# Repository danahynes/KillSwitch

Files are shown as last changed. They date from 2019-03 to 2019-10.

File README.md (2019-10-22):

# KillSwitch

Source code and binaries for the KillSwitch project
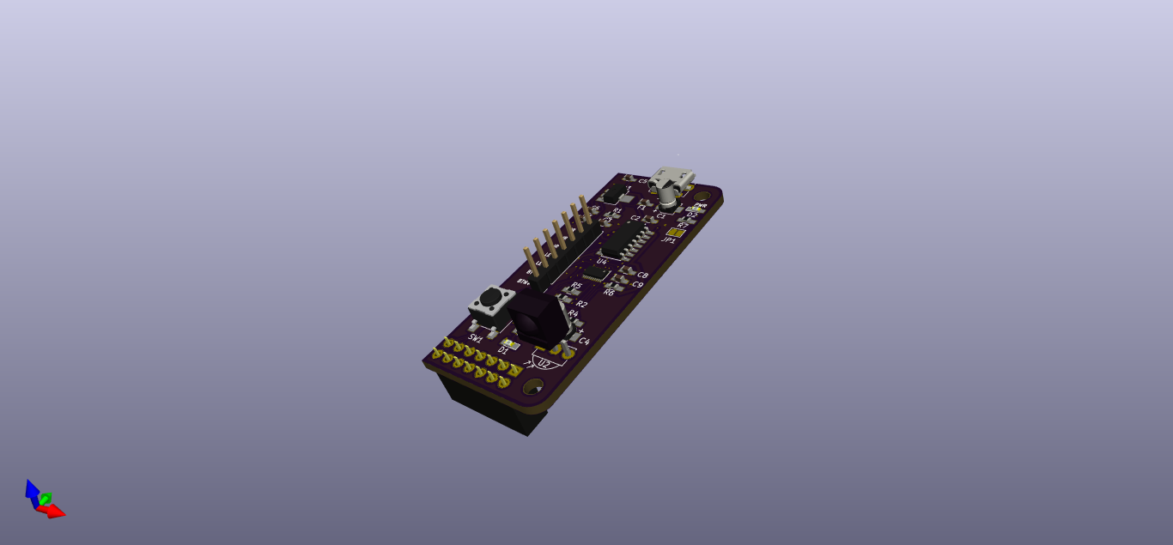
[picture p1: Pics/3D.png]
3D Image


## About
KillSwitch is a small PCB that attaches to your Raspberry Pi 2/3/4/0 (40 pin GPIO) and allows you to turn the Pi on or off using a push button or an IR remote. It is compatible with almost any infrared remote control, or IR blaster devices like the [Harmony Hub](https://www.logitech.com/en-us/product/harmony-hub) or
[SparkFun WiFi IR Blaster](https://www.sparkfun.com/products/15031). It has been tested with Raspbian and RetroPie. There are three parts to KillSwitch:

1. The hardware (the actual PCB)
2. The software (code that runs on the Raspberry Pi)
3. The firmware (code that runs on the PCB)

## Hardware
The first thing you need is the actual circuit board. The KillSwitch hardware files are included in the download, including a schematic and a PCB layout in KiCad 5 for both the Raspberry Pi 2/3/4 and the Zero. You can get the PCB made by the vendor of your choice (I used OSH Park, hence the purple PCB in the picture above) or breadboard it using the schematic.

## Software installation
To download and install the KillSwitch software on your Pi, first go to the [latest release](https://github.com/danahynes/KillSwitch/releases/latest). Click the link for the "Source code (zip)" or "Source code (tar.gz)" file. Download and extract the file. Then open a terminal, ```cd``` to the KillSwitch-N.N.N/Software/Bash folder, and type:
~~~~
sudo ./killswitch-install.sh
~~~~

Here is a one-line command that will do everything for you:
~~~~
cd && curl -O https://raw.githubusercontent.com/danahynes/KillSwitch/master/killswitch-install-latest.sh && bash killswitch-install-latest.sh
~~~~
You can safely delete the "killswitch-install-latest.sh" file in your home folder after rebooting.

You can also clone the latest "bleeding edge" code by running this command:
~~~~
git clone https://github.com/danahynes/KillSwitch
~~~~
then ```cd``` into the KillSwitch/Software/Bash folder and type:
~~~~
sudo ./killswitch-install.sh
~~~~

The software requires an OS of Raspbian Jessie or newer, or any other OS that
uses "systemd". If you're not sure, Google is your friend -)

## A note on the Pi serial ports
The Raspberry Pi has two UARTs, one based on hardware, and one based on software.

The hardware UART is faster and more reliable, since the silicon is specifically designed to do one thing, and one thing only, and do it well. On the Raspberry Pi 3 (and newer), this port is, by default, used for Bluetooth for obvious reasons.

The software UART on the Pi is normally used for serial login (the ability to log into, and control, the Pi over a wired RS-232 serial connection). This port is reconfigured by KillSwitch to allow communication between the device and the Pi.

That means that installing the software will turn off your ability to log in to the Pi using a serial console (getty/putty), as the software serial port (physical pins 8 and 10, labeled BCM 14 & BCM 15, and in Linux is known as /dev/ttyS0) is used to communicate to the device when using the settings script. If you don't know what this means, don't worry. You'll probably never use this feature. This does not affect the ability to use SSH or VNC to connect to the Pi, only to log in using getty or putty over a physical serial connection.

## Firmware installation
XXXXXXXXXXXXXXXXXXXXXXXXXXXXXXXXXXXX\
THIS DOES NOT WORK - NEED TO PROGRAM ATTINY BEFORE FIRST USE\
XXXXXXXXXXXXXXXXXXXXXXXXXXXXXXXXXXXX\
To install the firmware for the first time, you do not need a programmer, you can use the settings menu on the Pi. Make sure that the software is correctly installed on the Pi, then attach the KillSwitch device to your Pi. **Make sure to plug the power cord into the Pi, not the KillSwitch.** Open a terminal and type "killswitch-settings.sh". Then select the "Update" menu item. This will install/update the firmware on your device and the software on your Pi, if necessary.

## First use
To set up your KillSwitch for the first time, follow these steps:
1. After following the above steps to install the software and firmware, attach the KillSwitch to your Pi and plug the power source in to the KillSwitch. The KillSwitch device uses the same USB Micro B power supply that the Pi uses, so you just have to move the plug from the Pi to the KillSwitch.
2. Press and hold the push button on the device until the LED flashes rapidly (The default is 5 seconds, but this can be changed using the Settings program, see below). Release the button.
3. Point the remote at the device's IR receiver and press the button on the remote that you want to use as the "On" button (note that you have 15 seconds before the device exits the programming mode). The status LED will flash once slowly, then flash rapidly again.
4. Press the button on the remote that you want to use as the "Off" button (again, you have 15 seconds before the device exits programming mode). It can be the same as the "On" button if you wish, creating a "toggle" button. The status LED will flash twice slowly, then turn off.

During programming, the button works in the following ways:
* If the button is held for Long Press Time, exit Programming mode, leaving any unrecorded codes unchanged.
* If the button is pressed quickly, and you are currently recording the "On" code, the "On" code is left unchanged, and Programming is set to record a new "Off" code ("Skip code" in the table below).
* If the button is pressed quickly, and you are currently recording the "Off" code, the Programming mode is exited, and the new "Off" code is the same as the previously recorded "On" code ("Copy code" in the table below).

That's it! Your KillSwitch will now turn power on to the Pi when you press the "On" remote button, or press the hardware button once, and will safely shut down and power off when you press the "Off" remote button (or the "On" button again, if the buttons are the same), or press the hardware button again.

To change the remote codes, you can either shut down the Pi and repeat the steps above, or you can use the Settings program by typing in a terminal "killswitch-settings.sh" and selecting the "Start recording" option.

## Button operation
The hardware button on the KillSwitch device serves different purposes, depending on the state of the device and the Pi it is attached to. Here are its functions:

| Pi is | Button press | Button hold |
|---|---|---|
| Off | Pi boot | Program mode |
| On | Pi shutdown  | Reboot/Force Off |

| KillSwitch is | Button press | Button hold |
|---|---|---|
| Programming "On"  | Skip code | Exit programming |
| Programming "Off" | Copy code | Exit programming |

The hold time is configurable using "killswitch-settings.sh" and selecting the "Long Press Time" option. By default it is 5 seconds. The action of reboot/force off is also configurable through "killswitch-settings.sh", and selecting the "Long Press Action" option. The default is reboot.

## Settings
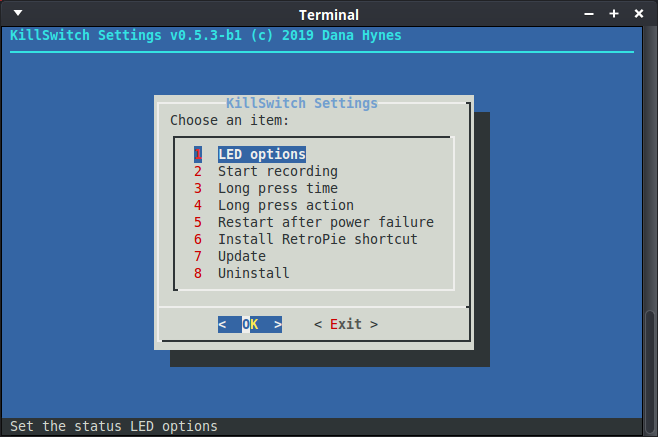
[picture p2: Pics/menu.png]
Menu Image
\
The KillSwitch device can be configured by opening a terminal and typing "killswitch-settings.sh" (or selecting the "KillSwitch" item from the RetroPie main menu). You can press "ESC" at any time to quit the program (Any current changes will not be saved).\
The following settings are available:

#### LED options
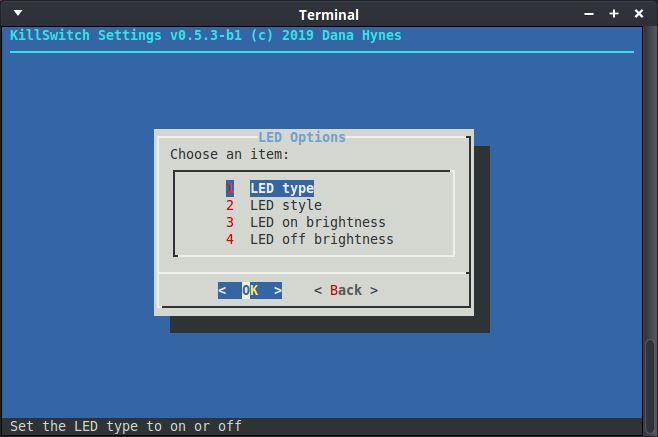
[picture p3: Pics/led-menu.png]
LED Menu Image
\
The LED on the KillSwitch is arguably the most configurable part of the device. Here you can set different options for the status LED on the KillSwitch.

###### LED type
* On (default) - the LED is at the "On" brightness when the Pi is on, and at the "Off" brightness when the Pi is off. You can set the "Off" brightness to a low value to have a dim "Standby" indicator, or 0 (the default) for completely off.
* Off - the LED is always off, unless the device is being programmed.

###### LED style
* Flash (default) - the LED flashes sharply from "On" brightness to completely off during bootup and shutdown.
* Pulse - the LED uses PWM to fade from completely off to "On" brightness and back to completely off during bootup and shutdown, giving a warm "glow" effect.

###### LED on brightness
Sets the brightness of the LED, from 0 to 255, when the LED flashes/pulses during the bootup/shutdown process or when the Pi is fully booted and running. Note that this setting does not affect the brightness of the LED during programming. The default is 255.

###### LED off brightness
Sets the brightness of the LED, from 0 to 255, when the Pi is completely shut down and powered off. The default is 0.

#### Start recording
Select this item and read the instructions that follow (or read the above section on "First use") to program the device to recognize new infrared remote commands to turn the Pi on and off.

#### Long press time
This setting determines how long, in seconds (from 1 to 10), the physical push button on the device must be held down to either start recording new codes, or reboot/force quit the Pi. The default is 5 seconds.

#### Long press action
Here you can set what happens when the physical push button on the device is held down for the Long Press Time when the Pi is running (see above). Holding the button down when the Pi is off will always enter programming mode.
* Reboot (default) - sends the "reboot" command the the Pi, which will safely shut down and restart. If the Pi is not responding, holding down the button may have no effect and you will need to remove the power plug from the device, or remove the device from the Pi to shut it off.
* Force quit - if you prefer to have the device cut the power completely to the Pi when it is not responding (same as pulling out the power plug), set this option. This option is useful if the power plug is not easily accessible, but the physical button is (for instance, an enclosure where the button is custom-mounted in a different location, see the below section about connector "J2").

#### Restart after power failure
This option lets you decide if the Pi is rebooted after an unexpected power failure. If this option is selected, and the the Pi was running, and power to the device was lost without a proper shutdown, KillSwitch will automagically boot the Pi once power is restored. If the option is unselected, you will need to use the physical button/remote button to turn the Pi back on after power is restored. This is a very handy feature if the Pi is used as a file/media server, or the button/power supply is inaccessible.

Note that the whole point of KillSwitch is that it is unsafe/unwise to simply remove power from the Pi without a safe shutdown. Therefore, the device will restore power to the Pi and attempt to boot it, however if the SD card in the Pi was corrupted during the power loss, it may not boot. The device will only restore power to the Pi, after that it's up to the Pi (and the integrity of its SD card) to decide if it will actually boot up.

This also applies to the sections above about reboot/force quit. The KillSwitch device only handles power, and can not adjust for SD card corruption. Your Mileage May Vary.

#### Install RetroPie shortcut
This option is used to place a shortcut named "KillSwitch" in the "Configuration" menu of RetroPie and allows you to access the Settings program using a plugged in/paired controller.

#### Update
This setting will attempt to update the software on your Pi, as well as the firmware in the device itself. It requires an internet connection to check for the latest release of the code on GitHub, then compares the GitHub version number to the version number running on the Pi/KillSwitch. If a newer version is available, you will be asked to confirm the update. The software will attempt to reprogram the device using ICSP, and then run the new installer.

If the update is successful, the Pi will ask to be rebooted. Press "Enter" at the end of the installer, wait for the reboot, and you'll be good to go!

Note that if you are using RetroPie, you will need an attached/paired keyboard to complete the process.

#### Uninstall
This one is pretty self-explanatory. It uninstalls almost all the files/folders from your Pi that were installed using the installer. If you use this option, please be sure to read the caveats at the end of the uninstall script output, as there are some things the uninstaller cannot revert, such as installed dependencies and the serial port options.

Note that if you are using RetroPie, you will need an attached/paired keyboard to complete the process.

## RetroPie
The software installed on your Pi is compatible with RetroPie. Where you see "killswitch-settings.sh" above, select "KillSwitch" from the main configuration menu.

When you install the software on a system that has RetroPie, a shortcut to "killswitch-settings.sh" will be installed in the main menu directory as "KillSwitch", where you can access it and use it with a paired game controller. Use the D-Pad to navigate between menu options, and the A/B buttons to accept/cancel. (So far it is tested on a Pi 3 B+ with RetroPie v4.4, but it should work on any newer Pi hardware and RetroPie software).

Specific buttons to use depend on your setup, but the defaults are that the A button is Enter (select OK/Back/Exit), and the B button is space bar (select option).

## Connectors
The connector labeled "J2" has 7 pins. These pins can be used to remotely locate the button/status LED/IR receiver. Starting with the pin closest to the physical push button, they are:

| Pin # | Label  | Connection |
|---|---|---|
| 1 | BTN +  | Physical push button +3.3v |
| 2 | BTN -  | Physical push button GND |
| 3 | LED +  | Status LED +3.3v |
| 4 | LED -  | Status LED GND |
| 5 | IR + | IR receiver +3.3v |
| 6 | IR SIG | IR receiver signal |
| 7 | IR - | IR receiver GND |

The connector labeled "J3" has 14 pins. These pins are normally used to connect to the Raspberry Pi's 40 pin GPIO header, but they can be used to remotely connect the device to the Pi, if necessary. The pins are numbered odd-even, starting from pin 1 (top right, when viewed from above, closest to the mounting hole). Looking at the connector from the top of the board, they are numbered:

| | | | | | | | |
|----|----|----|---|---|---|---|---|
| 13 | 11 | 9  | 7 | 5 | 3 | 1 | Mounting |
| 14 | 12 | 10 | 8 | 6 | 4 | 2 | Hole ( ) |

| Pin # | Label  | Connection |
|---|---|---|
| 1 | +3v3 | no connection |
| 2 | +5v | +5v to the Pi |
| 3 | BCM 2  | FEEDBACK |
| 4 | +5v | +5v to the Pi |
| 5 | BCM 3  | TRIGGER |
| 6 | GND | GND |
| 7 | BCM 4  | RESET (ICSP)  |
| 8 | BCM 14 | RX |
| 9 | GND | GND |
| 10 | BCM 15 | TX |
| 11 | BCM 17 | MOSI (ICSP) |
| 12 | BCM 18 | MISO (ICSP) |
| 13 | BCM 27 | SCK  (ICSP) |
| 14 | GND | GND |

FEEDBACK and TRIGGER are the connections used to sync the KillSwitch device to the Pi. TX and RX are the connections used to communicate between the device and the Pi when using the killswitch-settings app. ICSP connections are used to update the firmware on the device. +5v and GND are the connections used to power the Pi.

There is also a small set of jumper pads near the USB connector, labeled "JP1". These pads control whether the Power indicator LED is enabled. To enable the LED to indicate whether power is applied to the KillSwitch, place a small solder blob across these two pads. To disable the Power indicator LED, remove the solder blob.

The status LED on the KillSwitch can be disabled using the Settings app, as stated above. You can also turn off the Pi's power and activity LEDs for a truly "dark" experience using this link: https://www.jeffgeerling.com/blogs/jeff-geerling/controlling-pwr-act-leds-raspberry-pi (not tested, YMMV)

## Source code
The source code is arranged as an [Atom](https://ide.atom.io) project and the firmware is built using the [PlatformIO](https://platformio.org) plugin.

XXXXXXXXXXXXXXXXXXXXXXXXXXXXXX\
NEED TO PUT THIS REPO BACK UP\
XXXXXXXXXXXXXXXXXXXXXXXXXXXXXX\
If you want to compile the source for the firmware yourself, you'll also need to download the [Arduino-Libraries repo](https://github.com/danahynes/Arduino-Libraries/releases/latest).
You may also need to adjust the relative paths of the library file links in the Firmware/src/ folder since I use symlinks to the library files that reside outside this project. (I don't like having to copy/paste library directories every time I change something in one of them, so symlinks just pull in the latest version of a header or source file, from where it lives in a different repo folder on my build system. I know this isn't the most "correct" way to do it, and I could write a script to automate it or create Arduino packages, and maybe I will, but hey, for now... it works!)

## Licensing
KillSwitch makes use of the [IRremote library](https://github.com/z3t0/Arduino-IRremote) by Ken Shirriff, et al.
See Firmware/lib/IRremote/README.md for more info.

All other source code for the firmware, hardware, and software is copyright (c) 2019 Dana Hynes, and is licensed under the WTFPL v2. See the LICENSE file or http://www.wtfpl.net/ for more info.

Happy hacking!

# -)

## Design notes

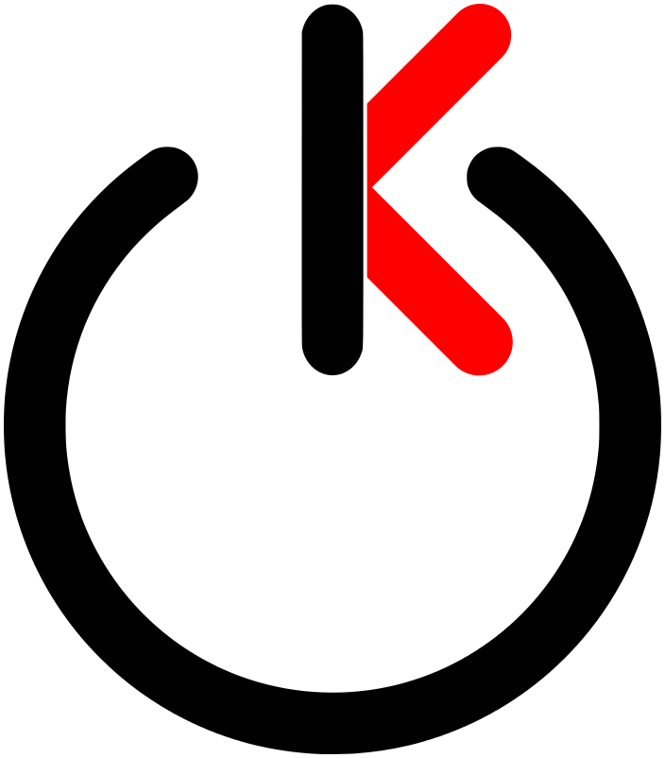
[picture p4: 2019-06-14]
Pics/killswitch.png

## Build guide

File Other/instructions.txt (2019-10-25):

1. killswitch-install-latest.py
    downloads latest release from GitHub and runs installer
2. killswitch-install.sh
    installs the rest of the scripts
    also called from killswitch-settings.sh when updating
    also called from killswitch-install-latest.sh when installing latest
3. killswitch-uninstall.sh
    uninstalls all this crap
    also called from killswitch-settings.sh when uninstalling
4. killswitch-settings.sh
    the pretty settings dialog script
5. killswitch-install-retropie.sh
    installs a shortcut in the retropie main config menu
    also called from killswitch-settings when doing menu install
    also called from killswitch-install.sh

6. killswitch-boot.service
    runs killswitch-boot.py at boot
7. killswitch-boot.py
    reads trigger inputs from hardware
8. killswitch-shutdown.service
    runs killswitch-shutdown.py at shutdown/reboot
9. killswitch-shutdown.py
    writes to feedback - one pulse for shutdown, two pulses for reboot

10. killswitch-settings.conf
    storage for settings script
    created on demand by killswitch-settings.sh
11. killswitch-avrdude.conf
    config file for programming avr over ICSP
    created by killswitch-install.sh

if we add a new setting:

add necessary EEPROM constants
add default value to firmware EEPROM in setup() if not 0
add serial code to firmware to read/write new setting in loop()
add code to software settings init to see if new setting has a value
if it's blank, write the default to the conf file

to create new release of master:

update number in Other/make-release.py
save
run Other/make-release.py

open/close killswitch-firmware_X.X.X.hex to stage it

commit/push

log into github
go to repo
click on releases above color bar
click draft new release
tag version should be vX.X.X
branch is master
write title as vX.X.X
write description
publish release

clone github repo on pi:

cd ~/Downloads; rm -rf KillSwitch; git clone https://github.com/danahynes/KillSwitch.git; cd KillSwitch/Software/Bash; sudo ./killswitch-install.sh

one-liner:

cd && curl -O https://raw.githubusercontent.com/danahynes/KillSwitch/master/killswitch-install-latest.sh && bash killswitch-install-latest.sh

reboot-test and shutdown-test use wiringPi gpio, not installed on RetroPie:
cd
git clone git://git.drogon.net/wiringPi
cd wiringPi
./build

loopback serial for testing:

./home/dana/Documents/Bash/terminaloop/terminaloop
OR
socat -d -d pty,raw,echo=0 pty,raw,echo=0

Arduino on laptop will be /dev/ttyAMX
close cutecom between programming

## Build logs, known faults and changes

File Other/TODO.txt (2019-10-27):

States.ods - need to know initial state of gpio's on Pi and arduino
    this will also determine if/where pullups or pulldowns are needed
Arduino trigger pin starts as input but floating
pi trigger pin starts as input floating or output high depending on tech source
    this should be fine as the arduino will have settled into output mode and
    the pi will become input and read arduino output when the script starts
arduino feedback pin starts as input but floating
pi feedback pin starts as input floating or output high depending on tech source
    this should be fine as the arduino will have settled into input pullup mode
    and is waiting for the pi to send a low at bootup
when the pi is done shutting down, what is the state of the feedback pin?
    the arduino has a pullup, but the pi may latch the pin to a low state

--------------------------------------------------------------------------------

DONE: write a script to do latest download/install and save it in top level to do
    one-liner
DONE: what to do with one-liner script after install???
    nothing, the redme tells users they can delete it after reboot

DONE: push external pin header to the right to avoid heatsink on cpu
DONE: line up with 3rd or 4th row from left
TEST: kicad custom logo for sheet/silkscreen need to be included
TEST: also default sheet? for logo in block
DONE: also include open hardware logo in blocks
DONE: place default text (name, copyright, all rights, WTFPL) in default sheet
DONE: finish pi zero pcb
DONE: kicad add dh_logo_silk.pretty to common folder (for my silkscreen footprint)
DONE: kicad add default sheet to common folder (for default sheet)
DONE: kicad add my logo/osh logo to common folder for new sheets
DONE: "designed with kicad" logo in block? (same as silkscreen)
DONE: kicad pi3/pi0 common folder for silkscreen footprint/sheet logos/default wks
DONE: pi0 README
DONE: we can remove logos for sheet i think? they are in the wks files as svg points
DONE: add JST and pins for power in

DONE: update: pi may reboot after update, do we deal with this?
    if user DOESN'T reboot, settings re-runs itself and shows new version number
    escaping from new version goes back to old? should we just bail? FORK!!!
DONE: update: retropie shortcut needs sudo to make symlink b/c /usr/local/bin is
    owned by root (wrong owner on ports folder)
NO: update: show installer output in tailbox? (still need sudo password in terminal)
    should really leave this as a terminal thing - works better

DONE: documentation on how the button/programming/led works
DONE: documentation on how to use settings
DONE: section headers (##) in main readme
DONE: documentation in main readme for device, description and usage
DONE: documentation in main readme for OSH license
DONE: documentation on button during programming:
    DONE: long press exits all
    DONE: short while recording on: skip, keep on code
    DONE: short while recording off: skip, off is same as on

DONE: error checking:
    DONE: killswitch-install.sh
    DONE: killswitch-uninstall.sh
    DONE: killswitch-install-latest.sh

DONE: firmware needs LED at 100% during programming, reset to On level afterwards
DONE: strip IRRemote to remove all decoding stuff - only need raw codes

DONE: fix relative paths? installer, uninstaller, any bash script

DONE: tell folks about pinout for female header so they can do custom wiring of
    PWR/GND/ICSP/serial/feedback/trigger

DONE: first step for install-latest, update is create .killswitch
    download everything there
    delete in error

DONE: convert install-latest to sh

DONE: killswitch-settings doActualUpdate runs install-latest

DONE: move firmware update from install-latest to killswitch-install
    same as in update, but don't ask for version numbers (always program)

DONE: move retropie shortcut from killswitch-settings to install-retropie
    then call it from settings and installer
    will also get called when running install-latest
    needs error checking

NO: firmware doesn't need version number in file name
    yes it does, since we can't put a string inside!

DONE: running install-latest and not reboot causes settings to scroll off screen -
    maybe don't fork it?

NO: convert install to py (what if user doesn't have py?)
NO: convert settings to py
NO: convert uninstall to py
DONE: convert make-release to py

DONE: end of update/install-latest -
    if we fork new settings, it scrolls off screen
    if we don't fork, exiting new settings brings us back to old settings

DONE: remove all ref's to keyboard: haven't needed it yet

DONE: download newest killswitch-install-latest in update
    don't copy over in install
    don't remove in uninstall

DONE: install retropie needs user for settings dir and chown
    could be run by user (settings) or sudo (installer)

DONE: settings needs error checking when running external
    (retropie, install, install-latest, uninstall)
DONE: also for downloading json for version check
DONE: also not using hardware/software error dialogs
DONE: finish doactualupdate

DONE: too much deleting in check_errors
    only return 1 from install-retropie
    does install-latest need deleting?
    or just install?

DONE: Install.sh - fix chown in avrdude
DONE:    Fix retropie install - needs folder check and echo "Installing retropie shortcut"

DONE: should we stop whole install if we can't set retropie shortcut?

DONE: move avrdude.conf to seperate file

DONE: Install.sh - back up old cmdline.txt to settings folder and restore
DONE:After uninstall
DONE:Will have old console setting from before install, whether console
DONE:Was on or not
DONE:Same for config.txt
DONE:Same for bash aliases
DONE: do apt-get cleanup after uninstall to remove unneeded deps

DONE: fix irremote/boarddefs.h to use timer 1 on 1634

man pages for all pi software scripts
kicad - template with block logos/osh park defaults

RGBW led
power led option/fed from uc
disable on board led if using remote
add pins for rgbw led on j2
make j2 5x2

settings safe exit - stop joy2key

how to delete if fail during install?
    can't remove everything, in case we are updating
    need to keep old files

how to delete as many files as possible after instsall?
    .killswitch/latest
    .killswitch/killswitch-install-latest
    ~/killswitch-install-latest

    one-liner/update: killswitch-install-latest should delete itself from where it was downloaded
        also delete latest folder
        won't run if install reboots
    download src/clone: killswitch-install should NOT DELETE ANYTHING

remove all ext's from scripts (to look/feel more like binaries)

test on retropie - what is A/B? A is enter.. B is ??? escape?
    update main readme

!!! WHAT THE FRESH HELL IS BREAKING /DEV/NULL ???

check if we are able to do a first-time programming on the atmega
    just put it in the installer, reprogram every time we run installer
        (should only be first install and update)
    we won't have a version number though
    do we use the version number from the actual device?
    using the one from the firmware won't work
    DONE: we also have no power unless we put a diode across the fet

make sure 14/15 point to software uart and bluetooth points to hardware uart
    (bluetooth is more important than talking to device)

pi 3:
/dev/ttyAMA0 - hardware serial - bluetooth
GPIO 14/15 - /dev/ttyS0 - software serial - enable_uart=1 - console login/getty
/dev/serial0 -> /dev/ttyS0
/dev/serial1 -> /dev/ttyAMA0
https://spellfoundry.com/2016/05/29/configuring-gpio-serial-port-raspbian-jessie-including-pi-3/

use pulses for trigger in killswitch-boot.py? (instead of timing length of button hold)
    first high - set everything up
    first low - start timer
    next high -
    next low - add to number of pulses, look at time elapsed

get arduino libs into firmware lib folder and remove symlinks
when building, check github for latest version of each lib
    if newer, download to libs folder
    then build

run file after reboot -
    in cmdline.txt, add init=/usr/local/bin/killswitch-run-once.py
    on run, remove that part from cmdline.txt
    show dialog that says "KillSwitch installed successfully"
    "do you want to run settings now? YES/NO"
    "you can run settings by opening a terminal and typing 'killswitch-settings.py'"
    "or use retropie port 'KillSwitch'"

make work with toggle (but let ppl know they can't futz with the switch during
    bootup/shutdown)
    https://retropie.org.uk/forum/topic/15727/tutorial-onoff-shim-exposed-neat-powerswitch-from-pimoroni

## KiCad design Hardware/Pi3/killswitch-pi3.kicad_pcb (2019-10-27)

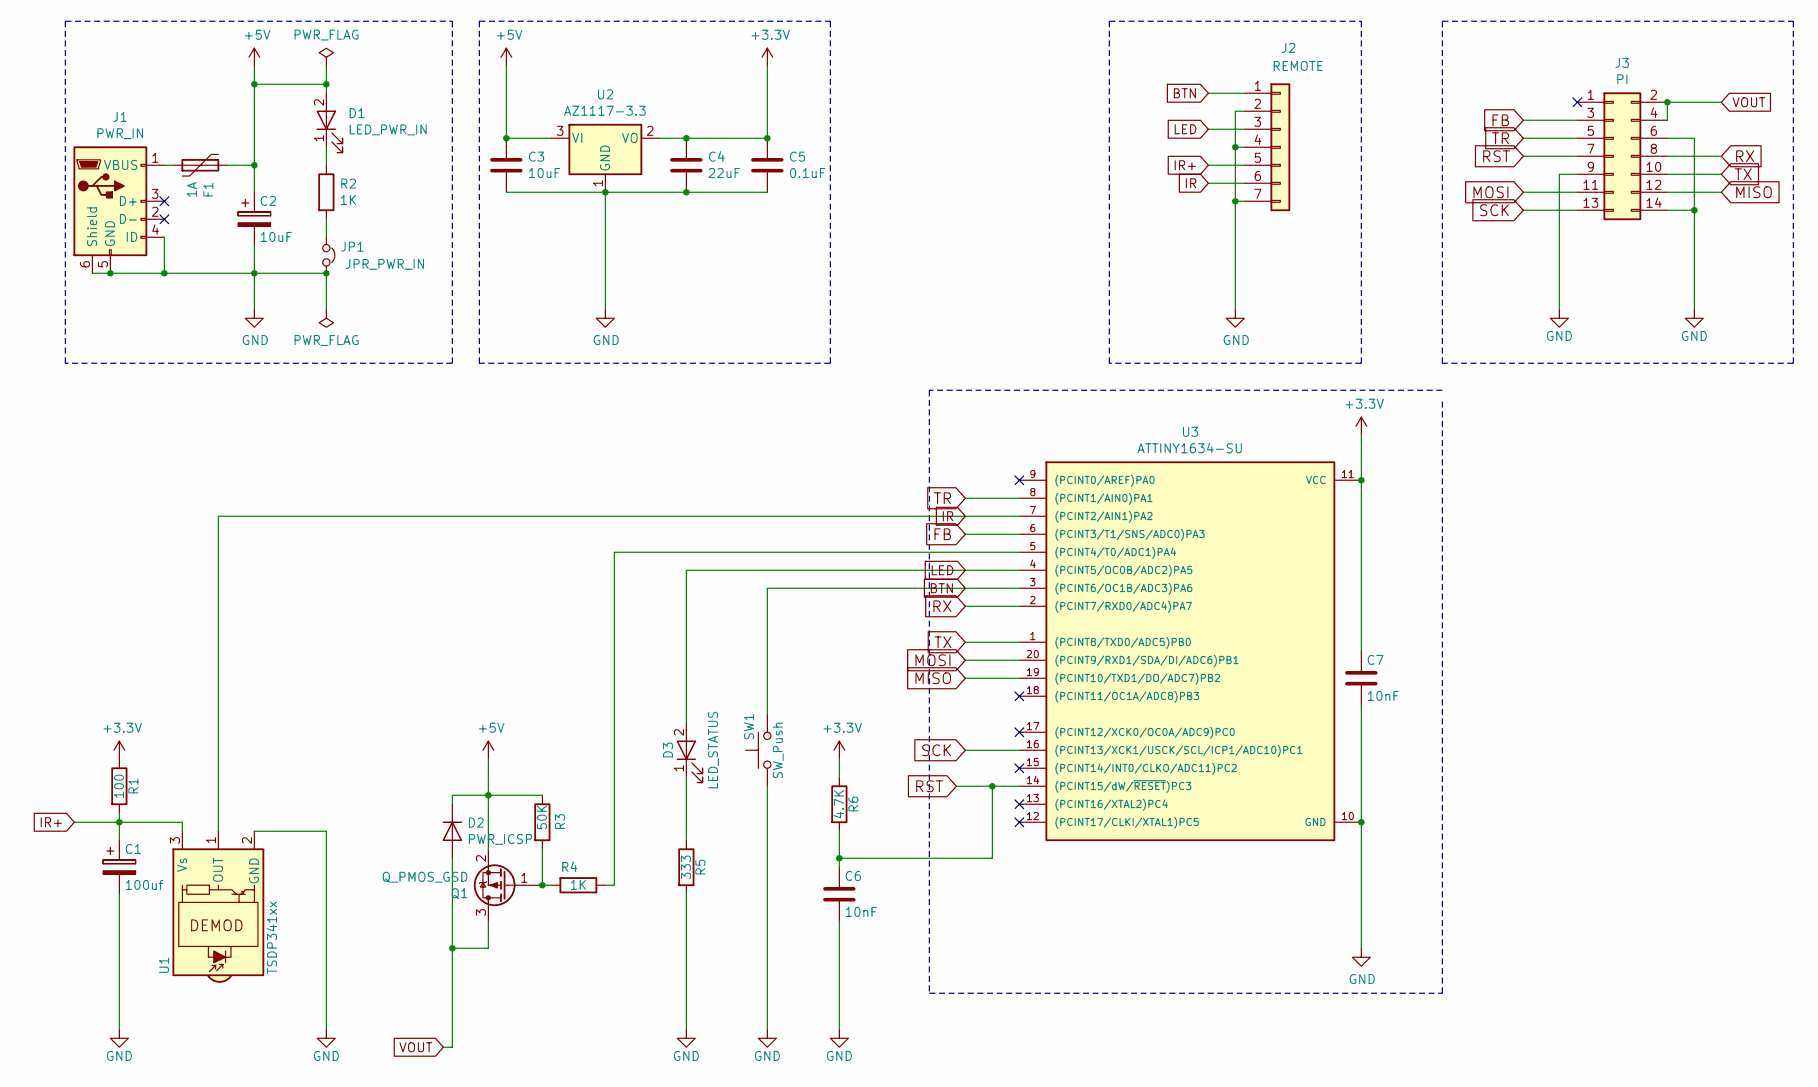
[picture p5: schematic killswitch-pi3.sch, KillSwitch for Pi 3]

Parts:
C1: 100uf; CP_Elec_3x5.3
C2: 10uF; CP_Elec_3x5.3
C3: 10uF; C_0603_HandSoldering
C4: 22uF; C_0603_HandSoldering
C5: 0.1uF; C_0603_HandSoldering
C6, C7: 10nF; C_0603_HandSoldering
D1: LED_PWR_IN; LED_0603_HandSoldering
D2: PWR_ICSP; D_0603
D3: LED_STATUS; LED_0603_HandSoldering
F1: 1A; C_0603_HandSoldering
J1: PWR_IN; USB_Micro-B_Molex-105017-0001
J2: REMOTE; Pin_Header_Straight_1x07_Pitch2.54mm
J3: PI; Socket_Strip_Straight_2x07_Pitch2.54mm
JP1: JPR_PWR_IN; SolderJumper-2_P1.3mm_Bridged_Pad1.0x1.5mm
Q1: Q_PMOS_GSD; SOT-323_SC-70_Handsoldering
R1: 100; R_0603_HandSoldering
R2, R4: 1K; R_0603_HandSoldering
R3: 50K; R_0603_HandSoldering
R5: 333; R_0603_HandSoldering
R6: 4.7K; R_0603_HandSoldering
SW1: SW_Push; SW_SPST_PTS645
U1: TSDP341xx; IRReceiver_Vishay_MOLD-3pin
U2: AZ1117-3.3; SOT-89-3_Handsoldering
U3: ATTINY1634-SU; SOIC-20W_7.5x12.8mm_Pitch1.27mm

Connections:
+3V3: C4.1, C5.1, C7.1, R1.1, R6.1, U2.2 (VO), U3.11 (VCC)
+5V: C2.1, C3.1, D1.2 (A), D2.1 (K), F1.2, Q1.2 (S), R3.1, U2.3 (VI)
BTN: J2.1, SW1.2, U3.3 ((PCINT6/OC1B/ADC3)PA6)
FB: J3.3, U3.6 ((PCINT3/T1/SNS/ADC0)PA3)
GND: C1.2, C2.2, C3.2, C4.2, C5.2, C6.2, C7.2, J1.4 (ID), J1.5 (GND), J1.6 (Shield), J2.2, J2.4, J2.7, J3.6, J3.9, J3.14, JP1.2, R5.2, SW1.1, U1.2 (GND), U2.1 (GND), U3.10 (GND)
IR: J2.6, U1.1 (OUT), U3.7 ((PCINT2/AIN1)PA2)
IR+: C1.1, J2.5, R1.2, U1.3 (Vs)
LED: D3.2 (A), J2.3, U3.4 ((PCINT5/OC0B/ADC2)PA5)
MISO: J3.12, U3.19 ((PCINT10/TXD1/DO/ADC7)PB2)
MOSI: J3.11, U3.20 ((PCINT9/RXD1/SDA/DI/ADC6)PB1)
unnamed: D1.1 (K), R2.1
unnamed: D3.1 (K), R5.1
unnamed: F1.1, J1.1 (VBUS)
unnamed: JP1.1, R2.2
unnamed: Q1.1 (G), R3.2, R4.2
unnamed: R4.1, U3.5 ((PCINT4/T0/ADC1)PA4)
RST: C6.1, J3.7, R6.2, U3.14 ((PCINT15/dW/~RESET~)PC3)
RX: J3.8, U3.2 ((PCINT7/RXD0/ADC4)PA7)
SCK: J3.13, U3.16 ((PCINT13/XCK1/USCK/SCL/ICP1/ADC10)PC1)
TR: J3.5, U3.8 ((PCINT1/AIN0)PA1)
TX: J3.10, U3.1 ((PCINT8/TXD0/ADC5)PB0)
VOUT: D2.2 (A), J3.2, J3.4, Q1.3 (D)

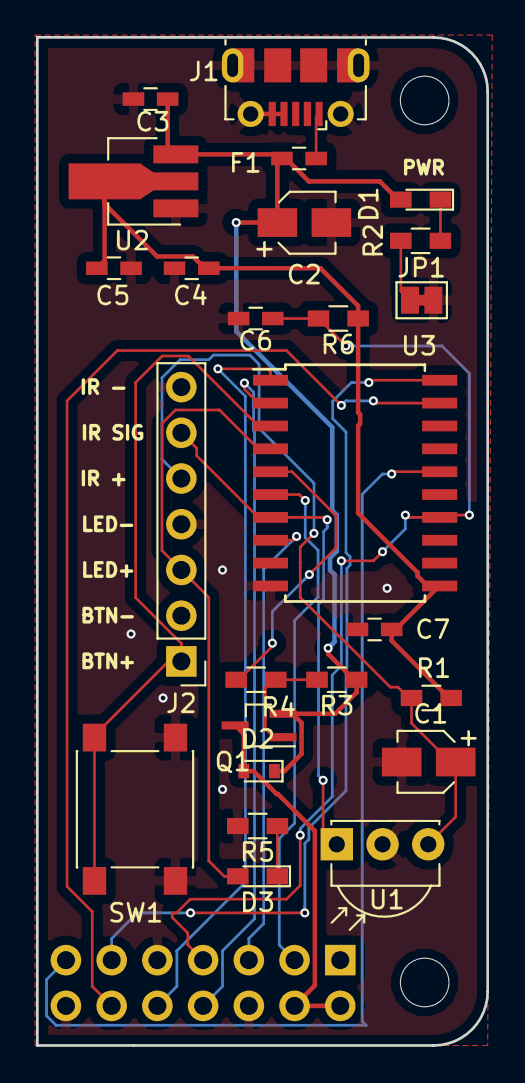
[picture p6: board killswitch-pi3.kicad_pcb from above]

Board: 2 copper layers, 25.0 x 56.0 mm, 26 parts (1 on the bottom side), 22 nets.

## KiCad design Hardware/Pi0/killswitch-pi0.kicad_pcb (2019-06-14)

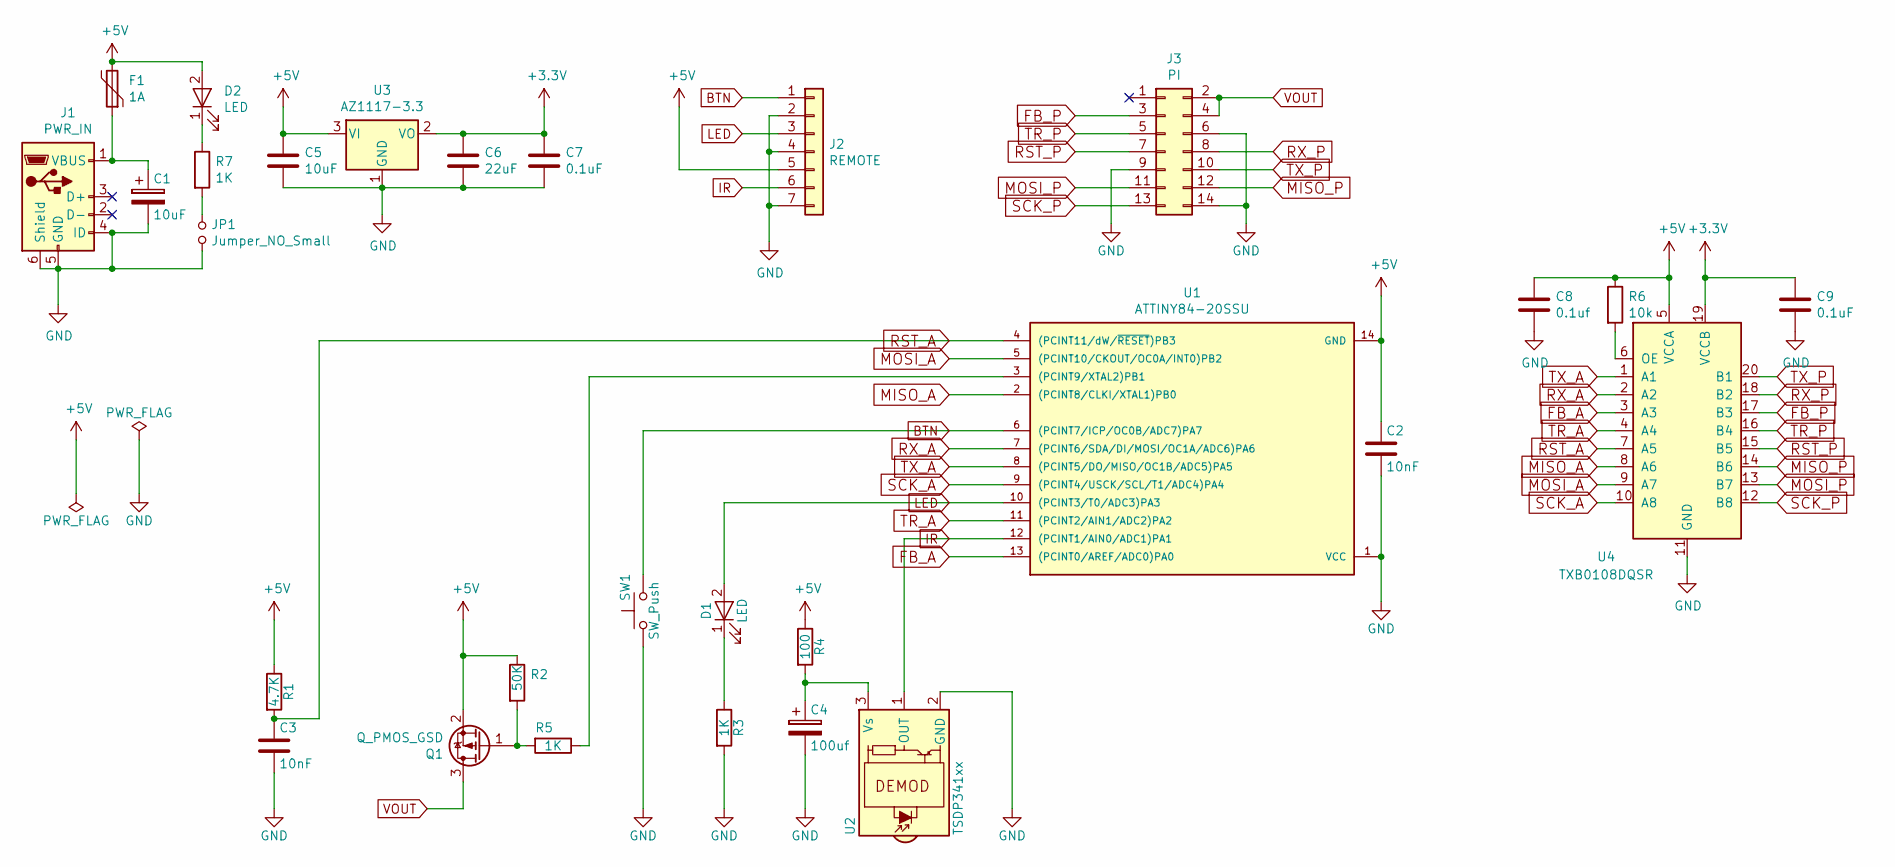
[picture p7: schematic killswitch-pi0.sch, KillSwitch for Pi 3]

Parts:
C1: 10uF; CP_Elec_3x5.3
C2, C3: 10nF; C_0603_HandSoldering
C4: 100uf; CP_Elec_3x5.3
C5: 10uF; C_0603_HandSoldering
C6: 22uF; C_0603_HandSoldering
C7, C9: 0.1uF; C_0603_HandSoldering
C8: 0.1uf; C_0603_HandSoldering
D1, D2: LED; LED_0603_HandSoldering
F1: 1A; C_0603_HandSoldering
J1: PWR_IN; USB_Micro-B_Molex-105017-0001
J2: REMOTE; Pin_Header_Straight_1x07_Pitch2.54mm
J3: PI; Socket_Strip_Straight_2x07_Pitch2.54mm
JP1: Jumper_NO_Small; SolderJumper-2_P1.3mm_Bridged2Bar_Pad1.0x1.5mm
Q1: Q_PMOS_GSD; SOT-323_SC-70_Handsoldering
R1: 4.7K; R_0603_HandSoldering
R2: 50K; R_0603_HandSoldering
R3, R5, R7: 1K; R_0603_HandSoldering
R4: 100; R_0603_HandSoldering
R6: 10k; R_0603_HandSoldering
SW1: SW_Push; SW_SPST_PTS645
U1: ATTINY84-20SSU; SOIC-14_3.9x8.7mm_Pitch1.27mm
U2: TSDP341xx; IRReceiver_Vishay_MOLD-3pin
U3: AZ1117-3.3; SOT-89-3_Handsoldering
U4: TXB0108DQSR; USON-20_2x4mm_Pitch0.4mm

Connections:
+3V3: C6.1, C7.1, C9.1, U3.2 (VO), U4.19 (VCCB)
+5V: C2.1, C5.1, C8.1, D2.2 (A), F1.2, J2.5, Q1.2 (S), R1.1, R2.1, R4.1, R6.1, U1.14 (GND), U3.3 (VI), U4.5 (VCCA)
BTN: J2.1, SW1.2, U1.6 ((PCINT7/ICP/OC0B/ADC7)PA7)
FB_A: U1.13 ((PCINT0/AREF/ADC0)PA0), U4.3 (A3)
FB_P: J3.3, U4.17 (B3)
GND: C1.2, C2.2, C3.2, C4.2, C5.2, C6.2, C7.2, C8.2, C9.2, J1.4 (ID), J1.5 (GND), J1.6 (Shield), J2.2, J2.4, J2.7, J3.6, J3.9, J3.14, JP1.2, R3.2, SW1.1, U1.1 (VCC), U2.2 (GND), U3.1 (GND), U4.11 (GND); also elsewhere on the board
IR: J2.6, U1.12 ((PCINT1/AIN0/ADC1)PA1), U2.1 (OUT)
LED: D1.2 (A), J2.3, U1.10 ((PCINT3/T0/ADC3)PA3)
MISO_A: U1.2 ((PCINT8/CLKI/XTAL1)PB0), U4.8 (A6)
MISO_P: J3.12, U4.14 (B6)
MOSI_A: U1.5 ((PCINT10/CKOUT/OC0A/INT0)PB2), U4.9 (A7)
MOSI_P: J3.11, U4.13 (B7)
unnamed 12: C1.1, F1.1, J1.1 (VBUS); also elsewhere on the board
unnamed: C4.1, R4.2, U2.3 (Vs)
unnamed: D1.1 (K), R3.1
unnamed: D2.1 (K), R7.1
unnamed: JP1.1, R7.2
unnamed: Q1.1 (G), R2.2, R5.2
unnamed: R5.1, U1.3 ((PCINT9/XTAL2)PB1)
unnamed: R6.2, U4.6 (OE)
RST_A: C3.1, R1.2, U1.4 ((PCINT11/dW/~RESET~)PB3), U4.7 (A5)
RST_P: J3.7, U4.15 (B5)
RX_A: U1.7 ((PCINT6/SDA/DI/MOSI/OC1A/ADC6)PA6), U4.2 (A2)
RX_P: J3.8, U4.18 (B2)
SCK_A: U1.9 ((PCINT4/USCK/SCL/T1/ADC4)PA4), U4.10 (A8)
SCK_P: J3.13, U4.12 (B8)
TR_A: U1.11 ((PCINT2/AIN1/ADC2)PA2), U4.4 (A4)
TR_P: J3.5, U4.16 (B4)
TX_A: U1.8 ((PCINT5/DO/MISO/OC1B/ADC5)PA5), U4.1 (A1)
TX_P: J3.10, U4.20 (B1)
VOUT: J3.2, J3.4, Q1.3 (D)

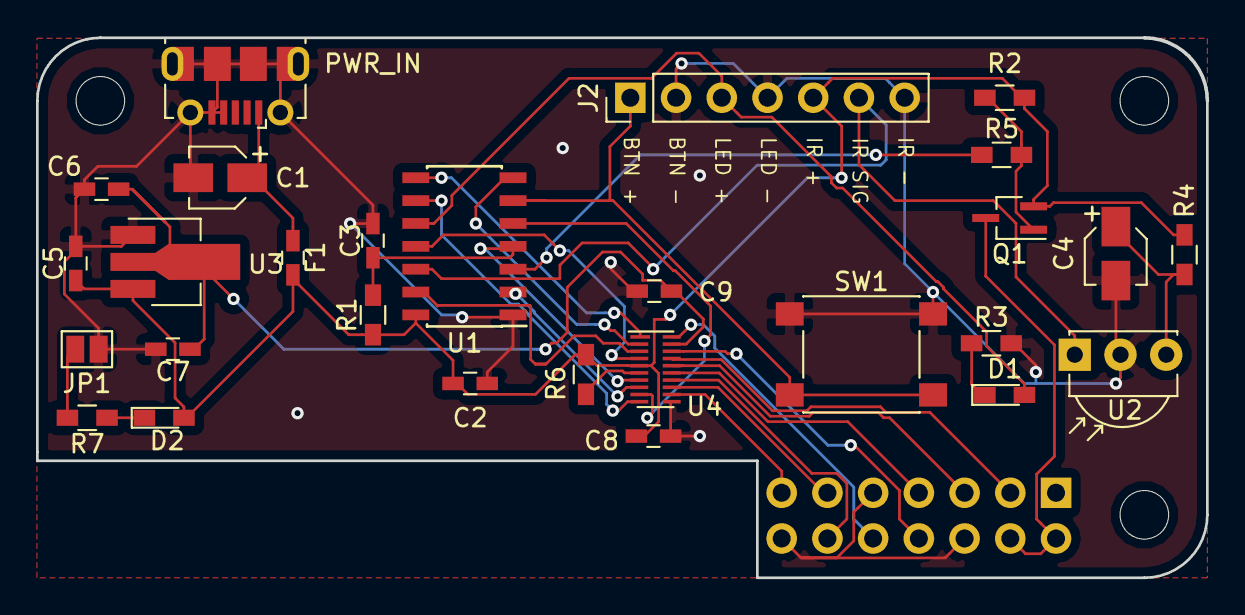
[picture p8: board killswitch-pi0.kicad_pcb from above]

Board: 2 copper layers, 65.0 x 30.0 mm, 29 parts (1 on the bottom side), 31 nets.

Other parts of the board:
PWR_IN: PWR_IN; USB_Micro-B_Molex-105017-0001

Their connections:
GND: PWR_IN.4, PWR_IN.5, PWR_IN.6; also elsewhere on the board
unnamed 12: PWR_IN.1; also elsewhere on the board

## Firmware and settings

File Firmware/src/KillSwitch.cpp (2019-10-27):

/*-----------------------------------------------------------------------------
 * KillSwitch.cpp
 * KillSwitch
 *
 * Copyright © 2019 Dana Hynes <danahynes@gmail.com>
 * This work is free. You can redistribute it and/or modify it under the terms
 * of the Do What The Fuck You Want To Public License, Version 2, as published
 * by Sam Hocevar. See the LICENSE file for more details.
 ----------------------------------------------------------------------------*/

//-----------------------------------------------------------------------------
// Includes

#include <Arduino.h>
#include <EEPROM.h>
#include <IRremote.h>
#include "DHButton.h"
#include "DHLED.h"
#include "DHTimer.h"
#include "DHPulseCounter.h"

//-----------------------------------------------------------------------------
// Defines

#define DH_DEBUG 1
#define ERASE_EEPROM 0
#define ARDUINO_UNO 1

//-----------------------------------------------------------------------------
// Constants

const char VERSION_NUMBER[] PROGMEM = "0.1.49";

const int STATE_OFF = 0;
const int STATE_BOOTING = 1;
const int STATE_ON = 2;
const int STATE_SHUTDOWN = 3;
const int STATE_REBOOT = 4;

const int PROG_STATE_NONE = 0;
const int PROG_STATE_CODE_ON = 1;
const int PROG_STATE_CODE_OFF = 2;

#if ARDUINO_UNO == 1

// pins for Arduino
const int PIN_BUTTON = 2;
const int PIN_IR = 7;
const int PIN_FEEDBACK = 5;
const int PIN_STATUS = 6;
const int PIN_TRIGGER = 13;
const int PIN_POWER = 4;

// NB: these pins are used to get around the fact that i broke the button
// on the shield - connect PIN_FEEDBACK to PIN_DEBUG_FEEDBACK_OUT, and connect
// PIN_DEBUG_FEEDBACK_IN to ground to simulate a feedback signal
const int PIN_DEBUG_FEEDBACK_OUT = 8;
const int PIN_DEBUG_FEEDBACK_IN = 9;
#else

// pins for ATTiny1634
const int PIN_BUTTON = 8;
const int PIN_IR = 0;
const int PIN_FEEDBACK = 3;
const int PIN_STATUS = 9;
const int PIN_TRIGGER = 7;
const int PIN_POWER = 10;
#endif

const int DEBOUNCE_DELAY = 50;
const int HOLD_TIME_DEFAULT = 5000;

const int STATUS_ON_BRIGHTNESS_DEFAULT = 255;
const int STATUS_TYPE_OFF = 1;

const int PROG_TIMEOUT = 15000;

const int EEPROM_ADDR_CODE_ON = 0;
const int EEPROM_ADDR_CODE_OFF = 4;
const int EEPROM_ADDR_SET_DEFAULT = 8;
const int EEPROM_ADDR_ON_BRIGHTNESS = 9;
const int EEPROM_ADDR_OFF_BRIGHTNESS = 10;
const int EEPROM_ADDR_TYPE = 11;
const int EEPROM_ADDR_PULSE = 12;
const int EEPROM_ADDR_HOLD_TIME = 13;
const int EEPROM_ADDR_HOLD_ACTION = 17;
const int EEPROM_ADDR_POWER_AFTER_FAIL = 18;
const int EEPROM_ADDR_POWER_WAS_ON = 19;

const int PULSE_CYCLE_SLOW = 500;
const int PULSE_CYCLE_FAST = 125;
const int FLASH_CYCLE_SLOW = 1000;
const int FLASH_CYCLE_FAST = 250;

const int TRIGGER_SHUTDOWN_TIME = 100;
const int TRIGGER_REBOOT_TIME = 500;

const char CMD_START = '?';
const char CMD_SEPERATOR = '|';
const char CMD_END = '!';

const int SERIAL_BUFF_SIZE = 8;

const int SERIAL_STATE_NONE = 0;
const int SERIAL_STATE_CMD = 1;
const int SERIAL_STATE_VALUE = 2;

const char SERIAL_LTP[] PROGMEM = "LTP"; // led type
const char SERIAL_LPL[] PROGMEM = "LPL"; // led pulse
const char SERIAL_LBN[] PROGMEM = "LBN"; // led on brightness
const char SERIAL_LBF[] PROGMEM = "LBF"; // led off brightness
const char SERIAL_REC[] PROGMEM = "REC"; // start recording
const char SERIAL_LPT[] PROGMEM = "LPT"; // long press time
const char SERIAL_LPA[] PROGMEM = "LPA"; // long press action
const char SERIAL_PWR[] PROGMEM = "PWR"; // reboot after power outage

//-----------------------------------------------------------------------------
// Variables

// states
int state = STATE_OFF;
int progState = PROG_STATE_NONE;

// hardware button
DHButton button(PIN_BUTTON, true, DEBOUNCE_DELAY);

#if ARDUINO_UNO == 1

// NB: fix for broken button
DHButton tmpFeedback(PIN_DEBUG_FEEDBACK_IN, true, DEBOUNCE_DELAY);
#endif

// ir receiver
IRrecv irrecv(PIN_IR);
decode_results results;

// pulse counter for feedback
DHPulseCounter feedbackCounter(PIN_FEEDBACK, LOW);

// status LED
DHLED ledStatus(PIN_STATUS);
int statusType = 0;
int statusPulse = 0;
byte onBright = 255;
byte offBright = 0;

// programming modes
bool progChanging = false;
bool progFlashStart = false;
DHTimer progTimer(PROG_TIMEOUT);

// trigger pin
DHTimer triggerTimer(TRIGGER_SHUTDOWN_TIME);

// serial connection
char serialCmd[SERIAL_BUFF_SIZE];
char serialValue[SERIAL_BUFF_SIZE];
int serialState = SERIAL_STATE_NONE;
int serialIndex = 0;

//------------------------------------------------------------------------------
// Functions

/*------------------------------------------------------------------------------
 * Writes a long value to EEPROM.
 ----------------------------------------------------------------------------*/
void EEPROMWriteLong(int address, long value) {
	byte four = (value & 0xFF);
	byte three = ((value >> 8) & 0xFF);
	byte two = ((value >> 16) & 0xFF);
	byte one = ((value >> 24) & 0xFF);

	EEPROM.update(address, four);
	EEPROM.update((address + 1), three);
	EEPROM.update((address + 2), two);
	EEPROM.update((address + 3), one);
}

/*-----------------------------------------------------------------------------
 * Reads a long value from EEPROM.
 ----------------------------------------------------------------------------*/
long EEPROMReadLong(long address) {
	long four = EEPROM.read(address);
	long three = EEPROM.read(address + 1);
	long two = EEPROM.read(address + 2);
	long one = EEPROM.read(address + 3);

	return (
		((four << 0) & 0xFF) +
		((three << 8) & 0xFFFF) +
		((two << 16) & 0xFFFFFF) +
		((one << 24) & 0xFFFFFFFF)
	);
}

/*-----------------------------------------------------------------------------
 * Sends a command-value pair over serial to the pi.
 ----------------------------------------------------------------------------*/
void sendSerial(char* CMD, char* VAL) {
	Serial.print(CMD_START);
	Serial.print(CMD);
	Serial.print(CMD_SEPERATOR);
	Serial.print(VAL);
	Serial.println(CMD_END);
}

/*-----------------------------------------------------------------------------
 * Puts the device into programming mode.
 ----------------------------------------------------------------------------*/
void startProgramming() {

	// set brightness to full for programming
	ledStatus.setLevel(255);

	// change prog state
	progState = PROG_STATE_CODE_ON;

#if DH_DEBUG == 1
	Serial.println(F("progState changed to PROG_STATE_CODE_ON"));
#endif

	// don't count flashes, start watchdog
	progChanging = false;
	progTimer.start();
}

/*-----------------------------------------------------------------------------
 * Takes the device out of programming mode.
 ----------------------------------------------------------------------------*/
void stopProgramming() {

	// change prog state
	progState = PROG_STATE_NONE;

	// reset brightness when done programming
	if (state == STATE_ON) {
		ledStatus.setLevel(onBright);
	} else {
		ledStatus.setLevel(offBright);
	}

#if DH_DEBUG == 1
	Serial.println(F("progState changed to PROG_STATE_NONE"));
#endif

	// don't count flashes, stop watchdog
	progChanging = false;
	progTimer.stop();
}

/*-----------------------------------------------------------------------------
 * Starts booting the pi.
 ----------------------------------------------------------------------------*/
void doBootup() {

	// guard block
	if (state == STATE_BOOTING) {
		return;
	}

	// set new state
	state = STATE_BOOTING;

	// reset brightness
	ledStatus.setLevel(onBright);

#if DH_DEBUG == 1
	Serial.println(F("state changed to STATE_BOOTING"));
#endif

	// feedback state to watch for when booting
	feedbackCounter.setValue(LOW);
}

/*-----------------------------------------------------------------------------
 * Starts shutting down the pi.
 ----------------------------------------------------------------------------*/
void doShutdown(bool changeTrigger = true) {

	// NB: this call handles the case where the pi sends a signal to
	// shutdown/reboot while we are programming ir codes. this can ONLY come
	// from the GUI, becuase the button/ir are busy doing programming tasks. it
	// is also an edge case since there is only a 30 second window (15s for on,
	// 15s for off) that the device can be in programming mode and still receive
	// a signal on the feedback line. But it seems necessary to ensure that the
	// pi and the device are in sync. Same for the reboot command.
	stopProgramming();

	// guard block
	if (state == STATE_SHUTDOWN) {
		return;
	}

	// set new state
	state = STATE_SHUTDOWN;

	// reset brightness
	ledStatus.setLevel(onBright);

#if DH_DEBUG == 1
	Serial.println(F("state changed to STATE_SHUTDOWN"));
#endif

	// feedback state to watch for when shutting down
	feedbackCounter.setValue(HIGH);

	if (changeTrigger) {

		// set the trigger state and starts its timer
		digitalWrite(PIN_TRIGGER, HIGH);
		triggerTimer.setTime(TRIGGER_SHUTDOWN_TIME);
		triggerTimer.start();
	}
}

/*-----------------------------------------------------------------------------
 * Reboots the pi.
 ----------------------------------------------------------------------------*/
void doReboot(bool changeTrigger = true) {

	// see above
	stopProgramming();

	// guard block
	if (state == STATE_REBOOT) {
		return;
	}

	// set new state
	state = STATE_REBOOT;

	// reset brightness
	ledStatus.setLevel(onBright);

#if DH_DEBUG == 1
	Serial.println(F("state changed to STATE_REBOOT"));
#endif

	// feedback state to watch for when rebooting
	feedbackCounter.setValue(LOW);

	if (changeTrigger) {

		// set the trigger state and starts its timer
		digitalWrite(PIN_TRIGGER, HIGH);
		triggerTimer.setTime(TRIGGER_REBOOT_TIME);
		triggerTimer.start();
	}
}

/*-----------------------------------------------------------------------------
 * Called when the button has been pressed for a short time (< hold time).
 ----------------------------------------------------------------------------*/
void doShortPress(DHButton* button) {

	// normal
	if (progState == PROG_STATE_NONE) {
		if (state == STATE_OFF) {
			doBootup();
		} else if (state == STATE_ON) {
			doShutdown();
		}

	// programming
	} else {

		if (progState == PROG_STATE_CODE_ON) {

			// NB: if we are waiting for an on code, and the button is pushed,
			// setting progChanging to true and continuing will cause the LED
			// to flash once, meaning we didn't record a code ("skip code")

			// count flashes, start watchdog
			progChanging = true;
			progTimer.start();
		} else if (progState == PROG_STATE_CODE_OFF) {

			// make off code same as on code ("copy code")
			long onCode = EEPROMReadLong(EEPROM_ADDR_CODE_ON);
			long offCode = onCode;
			EEPROMWriteLong(EEPROM_ADDR_CODE_OFF, offCode);

			// count flashes before exiting programming mode
			progChanging = true;
		}
	}
}

/*-----------------------------------------------------------------------------
 * Called when the button is held longer than the hold time.
 ----------------------------------------------------------------------------*/
void doLongPress(DHButton* button) {

	// normal
	if (progState == PROG_STATE_NONE) {

		// pi is on
		if (state == STATE_ON) {

			// get long press action
			bool forceQuitOnHold = EEPROM.read(EEPROM_ADDR_HOLD_ACTION);
			if (!forceQuitOnHold) {
				doReboot();
			} else {

				// force shutdown
				state = STATE_OFF;

				// store state for auto boot after power fail
				EEPROM.write(EEPROM_ADDR_POWER_WAS_ON, 0);

#if DH_DEBUG == 1
				Serial.println(F("state changed to STATE_OFF"));
#endif

			}

		// pi is off
		} else if (state == STATE_OFF) {
			startProgramming();
		}
	} else {

		// pi is programming, abort
		stopProgramming();
	}
}

#if ARDUINO_UNO == 1
/*-----------------------------------------------------------------------------
 * Called when the DEBUG feedback pin goes LOW.
 * This is used to prevent bounce on the pin when using a jumper by hand.
 ----------------------------------------------------------------------------*/
void doFeedbackPress(DHButton* button) {
	digitalWrite(PIN_DEBUG_FEEDBACK_OUT, LOW);
}

/*-----------------------------------------------------------------------------
 * Called when the DEBUG feedback pin goes HIGH.
 * This is used to prevent bounce on the pin when using a jumper by hand.
 ----------------------------------------------------------------------------*/
void doFeedbackRelease(DHButton* button) {
	digitalWrite(PIN_DEBUG_FEEDBACK_OUT, HIGH);
}
#endif

/*-----------------------------------------------------------------------------
 * Called when the trigger timer expires.
 ----------------------------------------------------------------------------*/
void doTriggerTimerUp(DHTimer* timer) {
	digitalWrite(PIN_TRIGGER, LOW);
}

/*-----------------------------------------------------------------------------
 * Called when the programming watchdog timer expires.
 ----------------------------------------------------------------------------*/
void doProgTimerUp(DHTimer* timer) {

	// abort programming
	stopProgramming();
}

/*-----------------------------------------------------------------------------
 * Called when the LED is done flashing for a count.
 ----------------------------------------------------------------------------*/
void doLEDDoneFlashing(DHLED* led) {

	// NB: delay() is bad but we need to differentiate between
	// the "waiting for code" flashes and the "got a code" flashes
	// is it worth a whole other timer/callback for this?

	// this is the "delay after slow flash"
	delay(FLASH_CYCLE_SLOW / 2);

	// stop counting flashes
	progFlashStart = false;
	progChanging = false;

	// switch from on code to off code
	if (progState == PROG_STATE_CODE_ON) {
		progState = PROG_STATE_CODE_OFF;

#if DH_DEBUG == 1
		Serial.println(F("progState changed to PROG_STATE_CODE_OFF"));
#endif

	} else if (progState == PROG_STATE_CODE_OFF) {

		// done with off code
		stopProgramming();
	}
}
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
void loop() {

//-----------------------------------------------------------------------------
// button

	button.update();

#if ARDUINO_UNO == 1

	// NB: fix for broken button
	tmpFeedback.update();
#endif

//-----------------------------------------------------------------------------
// ir

	if (irrecv.decode(&results)) {

#if DEBUG == 1
		Serial.println(results.value, HEX);
#endif

		if (results.value != REPEAT) {

			// normal on/off
			if (progState == PROG_STATE_NONE) {
				unsigned long onCode = EEPROMReadLong(EEPROM_ADDR_CODE_ON);
				unsigned long offCode = EEPROMReadLong(EEPROM_ADDR_CODE_OFF);
				if ((results.value == onCode) && (state == STATE_OFF)) {
					doBootup();
				} else if ((results.value == offCode) && (state == STATE_ON)) {
					doShutdown();
				}

			// programming
			} else {
				if (progState == PROG_STATE_CODE_ON) {
					long onCode = results.value;
					EEPROMWriteLong(EEPROM_ADDR_CODE_ON, onCode);

					// count flashes and start watchdog
					progChanging = true;
					progTimer.start();
				} else if (progState == PROG_STATE_CODE_OFF) {
					long offCode = results.value;
					EEPROMWriteLong(EEPROM_ADDR_CODE_OFF, offCode);

					// count flashes before exiting programming mode
					progChanging = true;
				}
			}
		}

		// get the next code
		irrecv.resume();
	}

//-----------------------------------------------------------------------------
// feedback

	feedbackCounter.update();

//-----------------------------------------------------------------------------
// status

	// normal
	if (progState == PROG_STATE_NONE) {

		// if not programming, led always off
		if (statusType == STATUS_TYPE_OFF) {
			ledStatus.off();
		} else {

			// states that require flashing
			if ((state == STATE_BOOTING) ||
					(state == STATE_SHUTDOWN) ||
					(state == STATE_REBOOT)) {

				// flash/pulse slow
				if (ledStatus.getState() != ledStatus.FLASHING) {
					if (statusPulse) {
						ledStatus.setOnTime(PULSE_CYCLE_SLOW / 2);
						ledStatus.setOffTime(PULSE_CYCLE_SLOW / 2);
						ledStatus.setFadeOnTime(PULSE_CYCLE_SLOW / 2);
						ledStatus.setFadeOffTime(PULSE_CYCLE_SLOW / 2);
					} else {
						ledStatus.setOnTime(FLASH_CYCLE_SLOW / 2);
						ledStatus.setOffTime(FLASH_CYCLE_SLOW / 2);
					}
					ledStatus.flash(statusPulse);
				}

			// no flashing
			} else {
				ledStatus.on();
			}
		}

	// programming flash
	} else {

		// slow flash for confirmation
		if (progChanging) {

			// put the led in a known state and start a new cycle
			if (progFlashStart == false) {
				progFlashStart = true;

				// off for half cycle before flash
				ledStatus.off();

				// NB: delay() is bad but we need to differentiate between
				// the "waiting for code" flashes and the "got a code" flashes
				// is it worth a whole other timer/callback for this?
				//
				// this is the "delay before slow flash"
				delay(FLASH_CYCLE_SLOW / 2);

				// flash/pulse slow
				if (statusPulse) {
					ledStatus.setOnTime(PULSE_CYCLE_SLOW / 2);
					ledStatus.setOffTime(PULSE_CYCLE_SLOW / 2);
					ledStatus.setFadeOnTime(PULSE_CYCLE_SLOW / 2);
					ledStatus.setFadeOffTime(PULSE_CYCLE_SLOW / 2);
				} else {
					ledStatus.setOnTime(FLASH_CYCLE_SLOW / 2);
					ledStatus.setOffTime(FLASH_CYCLE_SLOW / 2);
				}

				// flash for count
				if (progState == PROG_STATE_CODE_ON) {
					ledStatus.flashForCount(1, statusPulse);
				} else if (progState == PROG_STATE_CODE_OFF) {
					ledStatus.flashForCount(2, statusPulse);
				}
			}

		// not changing, just waiting for a code
		} else {

			// flash fast
			if (ledStatus.getState() != ledStatus.FLASHING) {
				if (statusPulse) {
					ledStatus.setOnTime(PULSE_CYCLE_FAST / 2);
					ledStatus.setOffTime(PULSE_CYCLE_FAST / 2);
					ledStatus.setFadeOnTime(PULSE_CYCLE_FAST / 2);
					ledStatus.setFadeOffTime(PULSE_CYCLE_FAST / 2);
				} else {
					ledStatus.setOnTime(FLASH_CYCLE_FAST / 2);
					ledStatus.setOffTime(FLASH_CYCLE_FAST / 2);
				}
				ledStatus.flash(statusPulse);
			}
		}
	}

	ledStatus.update();

//-----------------------------------------------------------------------------
// trigger

	triggerTimer.update();

//-----------------------------------------------------------------------------
// power

	// states that do not require pi to be powered
	if (state == STATE_OFF) {
		digitalWrite(PIN_POWER, LOW);
	} else {
		digitalWrite(PIN_POWER, HIGH);
	}

//-----------------------------------------------------------------------------
// prog watchdog

	progTimer.update();

//-----------------------------------------------------------------------------
// serial input

	if (Serial.available()) {

		// get next char in serial buffer
		char c = Serial.read();

		// command start
		if (c == CMD_START) {
			serialState = SERIAL_STATE_CMD;
			memset(serialCmd, 0, SERIAL_BUFF_SIZE);
			memset(serialValue, 0, SERIAL_BUFF_SIZE);
			serialIndex = 0;

		// command end, value start
		} else if (c == CMD_SEPERATOR) {
			serialState = SERIAL_STATE_VALUE;
			serialIndex = 0;

		// value end
		} else if (c == CMD_END) {
			serialState = SERIAL_STATE_NONE;
			serialIndex = 0;

#if DH_DEBUG == 1
			Serial.print(F("Serial cmd: "));
			Serial.println(serialCmd);
			Serial.print(F("Serial val: "));
			Serial.println(serialValue);
#endif

			// check which command we got
			if (strcmp_P(serialCmd, SERIAL_LTP) == 0) {
				int ltp = atoi(serialValue);

				// will take effect in next update()
				EEPROM.update(EEPROM_ADDR_TYPE, ltp);
				statusType = ltp;
			} else if (strcmp_P(serialCmd, SERIAL_LPL) == 0) {
				int lpl = atoi(serialValue);

				// will take effect in next update()
				EEPROM.update(EEPROM_ADDR_PULSE, lpl);
				statusPulse = lpl;
			} else if (strcmp_P(serialCmd, SERIAL_LBN) == 0) {
				int lbn = atoi(serialValue);

				// will take effect in next update()
				EEPROM.update(EEPROM_ADDR_ON_BRIGHTNESS, lbn);
				onBright = lbn;
			} else if (strcmp_P(serialCmd, SERIAL_LBF) == 0) {
				int lbf = atoi(serialValue);

				// will take effect in next update()
				EEPROM.update(EEPROM_ADDR_OFF_BRIGHTNESS, lbf);
				offBright = lbf;
			} else if (strcmp_P(serialCmd, SERIAL_REC) == 0) {
				startProgramming();
			} else if (strcmp_P(serialCmd, SERIAL_LPT) == 0) {
				unsigned long lpt = atol(serialValue);

				EEPROMWriteLong(EEPROM_ADDR_HOLD_TIME, lpt);
				button.setHoldTime(lpt);
			} else if (strcmp_P(serialCmd, SERIAL_LPA) == 0) {
				int lpa = atoi(serialValue);

				// will take effect in next doLongPress()
				EEPROM.update(EEPROM_ADDR_HOLD_ACTION, lpa);
			} else if (strcmp_P(serialCmd, SERIAL_PWR) == 0) {
				int pwr = atoi(serialValue);

				// will take effect in next setup()
				EEPROM.update(EEPROM_ADDR_POWER_AFTER_FAIL, pwr);
			}

		// build up command or value
		} else {
			if (serialState == SERIAL_STATE_CMD) {
				serialCmd[serialIndex++] = c;
			} else if (serialState == SERIAL_STATE_VALUE) {
				serialValue[serialIndex++] = c;
			}
		}
	}
}

// -)

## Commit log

2019-01-25 switch to atom
2019-01-25 moved ks arduino to platformio
2019-01-27 added option to turn led off completely except for programming
2019-02-05 lots of changes
    added defines for debug/erase
    moved strings to progmem
    cleaned up old code
    cleaned up doCounterDone
    added temp button for feedback testing
    added eeprom erase in setup
    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
2019-02-06 fixed getting raw strings from flash
    [KillSwitch.cpp]
2019-02-06 read real version from arduino
2019-02-12 lots of changes
    new version number
    remove STATE_PROGRAMMING
    change buuton pin for broken button
    add status type
    change eeprom addresses
    change shutdown/reboot time
    change serial commands
    remove beforeProgState
    add reset brightness for off brightness
    add delay after program confirm flash
    [KillSwitch.cpp]
2019-02-14 changed led menu and added off brightness
2019-02-14 change arduino to firmware
2019-02-16 moved kicad into this repo
    [killswitch_84.kicad_pcb, killswitch_84.sch]
2019-02-18 added logo to pcb and sheets
    [killswitch_84.kicad_pcb, killswitch_84.sch]
2019-02-18 change folder names
    [killswitch_84.kicad_pcb, killswitch_84.sch]
2019-02-21 updated pcb
    [killswitch_84.kicad_pcb]
2019-02-21 added 3d view of ir receiver and hang tabs for usb connector
    [killswitch_84.kicad_pcb, killswitch_84.sch]
2019-02-21 added pins to header for ir
    [killswitch_84.kicad_pcb, killswitch_84.sch]
2019-02-22 final rev 3 board
    [killswitch_84.kicad_pcb, killswitch_84.sch]
2019-02-23 moved version/build info down
    [killswitch_84.kicad_pcb]
2019-02-23 changed version system
    [killswitch_84.kicad_pcb, killswitch_84.sch]
2019-02-25 rc for changing the update code (again)
    [killswitch_84.kicad_pcb, killswitch_84.sch]
2019-02-26 other now included in repo
    [States.ods]
2019-02-26 updated version number
    [killswitch_84.kicad_pcb, killswitch_84.sch]
2019-02-28 added OSH logo/changed version number
    [killswitch_84.kicad_pcb]
2019-02-28 changed release date
    [killswitch_84.sch]
2019-02-28 fixed typo
    [killswitch_84.kicad_pcb, killswitch_84.sch]
2019-02-28 revert version number
    [killswitch_84.kicad_pcb, killswitch_84.sch]
2019-03-05 added power on after power failure code
    [KillSwitch.cpp]
2019-03-05 change version number
    [killswitch_84.kicad_pcb]
2019-03-05 added boot after power failure code
2019-03-05 new build
    [killswitch_84.kicad_pcb, killswitch_84.sch]
2019-03-10 moved external btn/led/ir connector
    [killswitch_84.kicad_pcb]
2019-03-10 finished PCB todos
2019-03-12 new date
    [killswitch_84.kicad_pcb]
2019-03-12 version bump
    [killswitch_84.kicad_pcb]
2019-03-12 logos for sheet block/silkscreen are now local
    [killswitch_84.kicad_pcb]
2019-03-13 added license info to block
    [killswitch_84.kicad_pcb, killswitch_84.sch]
2019-03-15 added open source hardware logo to sheet blocks and back of pcb
    [killswitch_84.kicad_pcb]
2019-03-15 changes osh logo to have text like pcb
2019-03-16 try to fix esc in new version going back to old
2019-03-16 switch settings to py
2019-03-18 fixed typo in setuid
    [killswitch_84.kicad_pcb, killswitch_84.sch]
2019-03-18 fix ports folder permissions so no more setuid
    [killswitch_84.kicad_pcb, killswitch_84.sch]
2019-03-18 final fix for retropie shortcut
    [killswitch_84.kicad_pcb, killswitch_84.sch]
2019-03-19 import locale in install-latest.py
    [killswitch_84.kicad_pcb, killswitch_84.sch]
2019-03-19 fix typo in install-latest.py
    [killswitch_84.kicad_pcb, killswitch_84.sch]
2019-03-19 remove one-liner after use
    [killswitch_84.kicad_pcb, killswitch_84.sch]
2019-03-20 renamed hardware files
    [killswitch-pi3.kicad_pcb, killswitch-pi3.sch]
2019-03-20 moved hardware files
    [killswitch-pi3.kicad_pcb, killswitch-pi3.sch, killswitch_84.kicad_pcb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]
2019-03-20 move kicad logos to correct folders
2019-03-22 added pcb files for pi zero
    [killswitch-pi0.kicad_pcb, killswitch-pi0.sch, killswitch-pi3.kicad_pcb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]
2019-03-23 converted make-release to python
    [killswitch-pi0.kicad_pcb, killswitch-pi0.sch, killswitch-pi3.kicad_pcb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]
2019-03-25 added error checking to scripts
    [killswitch-pi0.kicad_pcb, killswitch-pi0.sch, killswitch-pi3.kicad_pcb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]
2019-03-27 led always at 100% brightness for programming
2019-03-30 update for 14 pin pi connector
2019-04-03 added diode to backpower the killswitch from the pi (for programming)
    [killswitch-pi3.kicad_pcb, killswitch-pi3.sch]
2019-04-25 add stage numbers to fail points
2019-04-27 fixed quoting issue in led type help string
2019-04-27 added esc to settings description
2019-05-09 added prints/removed cruft/no forking of installer
2019-05-10 version bump for update test
    [killswitch-pi0.kicad_pcb, killswitch-pi0.sch, killswitch-pi3.kicad_pcb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]
2019-05-11 swap pins to be more like attiny84
    [killswitch-pi3.kicad_pcb, killswitch-pi3.sch]
2019-05-14 first public release
    [killswitch-pi0.kicad_pcb, killswitch-pi0.sch, killswitch-pi3.kicad_pcb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]
2019-05-14 minor edits
    [killswitch-pi0.kicad_pcb, killswitch-pi0.sch, killswitch-pi3.kicad_pcb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]
2019-05-17 first test of retropie
    [killswitch-pi3.kicad_pcb, killswitch-pi3.sch]
2019-05-23 retropie test
    [killswitch-pi0.kicad_pcb, killswitch-pi0.sch, killswitch-pi3.kicad_pcb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]
2019-06-02 install-latest.sh test
    [killswitch-pi0.kicad_pcb, killswitch-pi0.sch, killswitch-pi3.kicad_pcb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]
2019-10-22 Clean up schematic/remove level shifter
    [killswitch-pi0.sch, killswitch-pi3.kicad_pcb, killswitch-pi3.sch]
2019-10-25 changed to ATTiny1634
    [killswitch-pi3.kicad_pcb, killswitch-pi3.sch]
2019-10-25 minor edits/fixed long press time change in serial
    [KillSwitch.cpp]
2019-10-27 new schematic/pcb for 1634
    [killswitch-pi3.kicad_pcb, killswitch-pi3.sch]
2019-10-27 pin change for better pcb layout
2019-10-27 added 1634 to board defs
